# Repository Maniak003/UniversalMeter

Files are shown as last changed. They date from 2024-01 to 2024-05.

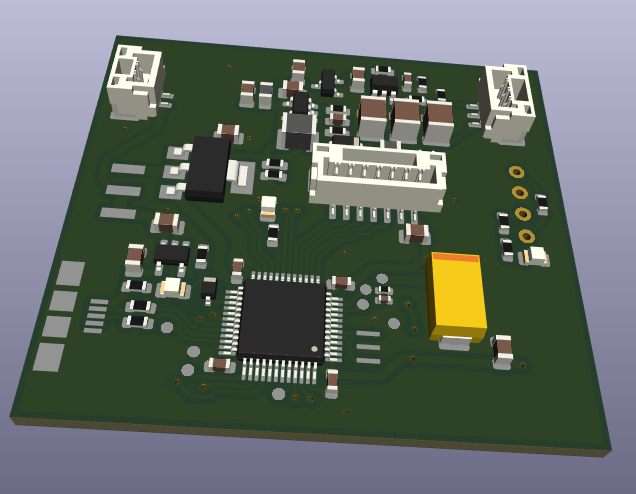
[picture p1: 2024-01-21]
Documents/bot_board.png

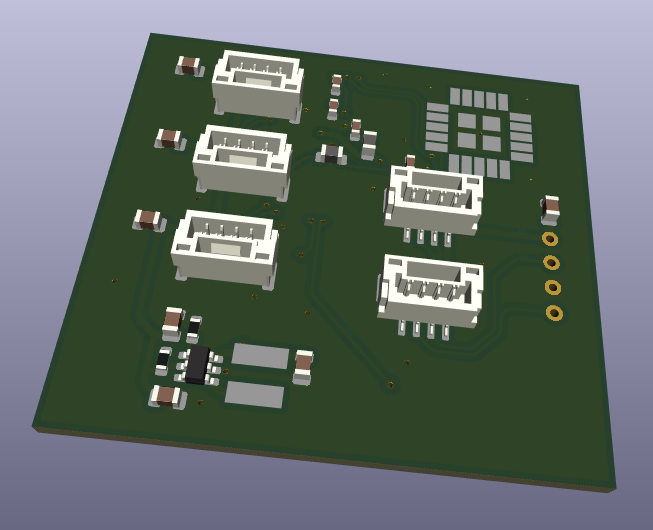
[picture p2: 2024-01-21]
Documents/top_board.png

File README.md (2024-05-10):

<!DOCTYPE html>
<html lang="en" data-color-mode="auto" data-light-theme="light" data-dark-theme="dark">
  <head>
    <meta charset="utf-8">
  </head>
    <body class="logged-in env-production page-responsive page-blob" style="word-wrap: break-word;">
      <p> Many sensors in one device.</p>
      <a href="https://github.com/Maniak003/UniversalMeter/wiki/Description" rel="nofollow">
        BluZ
      </a>
    </body>
</html>

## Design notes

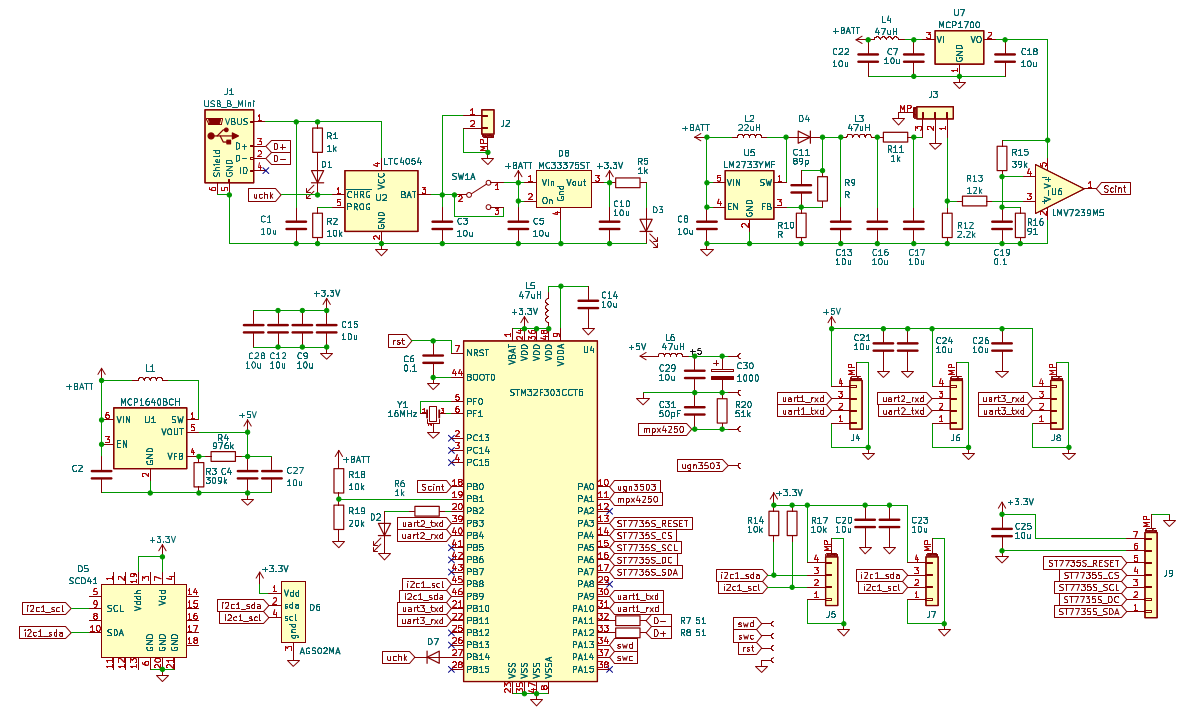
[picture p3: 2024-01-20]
kicad/AirAnalizer/AirAnalizer.png

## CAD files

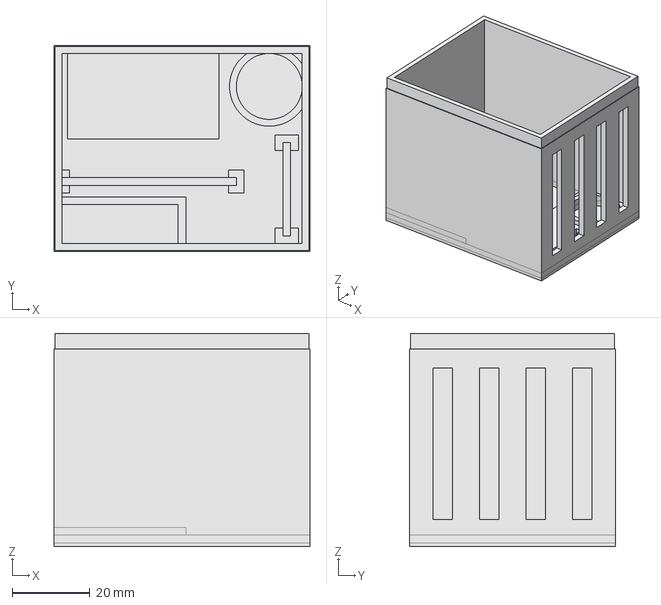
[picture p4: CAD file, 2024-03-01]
FreeCAD/base.FCStd
66.0 x 53.0 x 55.0 mm

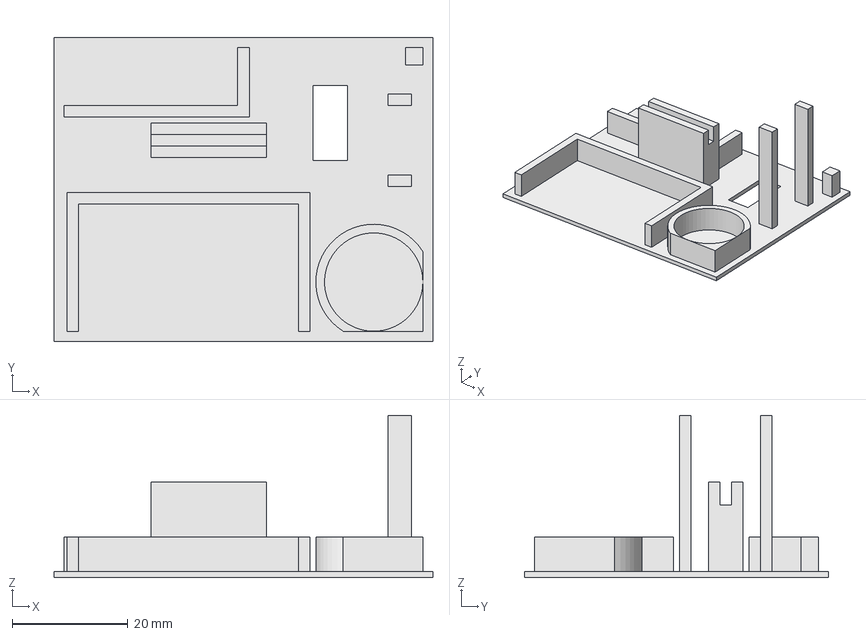
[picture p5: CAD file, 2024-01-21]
FreeCAD/base_top.FCStd
65.5 x 52.5 x 28.0 mm

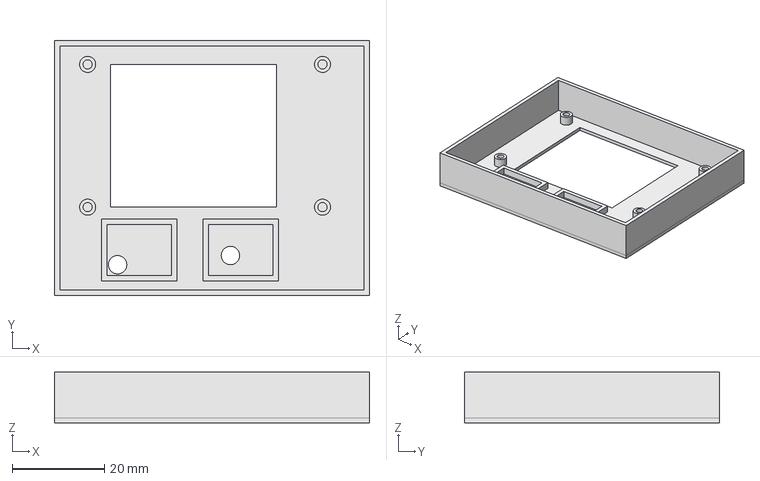
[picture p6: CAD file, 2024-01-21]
FreeCAD/cover.FCStd
68.4 x 55.4 x 11.0 mm

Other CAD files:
FreeCAD/base2.stl
FreeCAD/base.stl
FreeCAD/cover.stl

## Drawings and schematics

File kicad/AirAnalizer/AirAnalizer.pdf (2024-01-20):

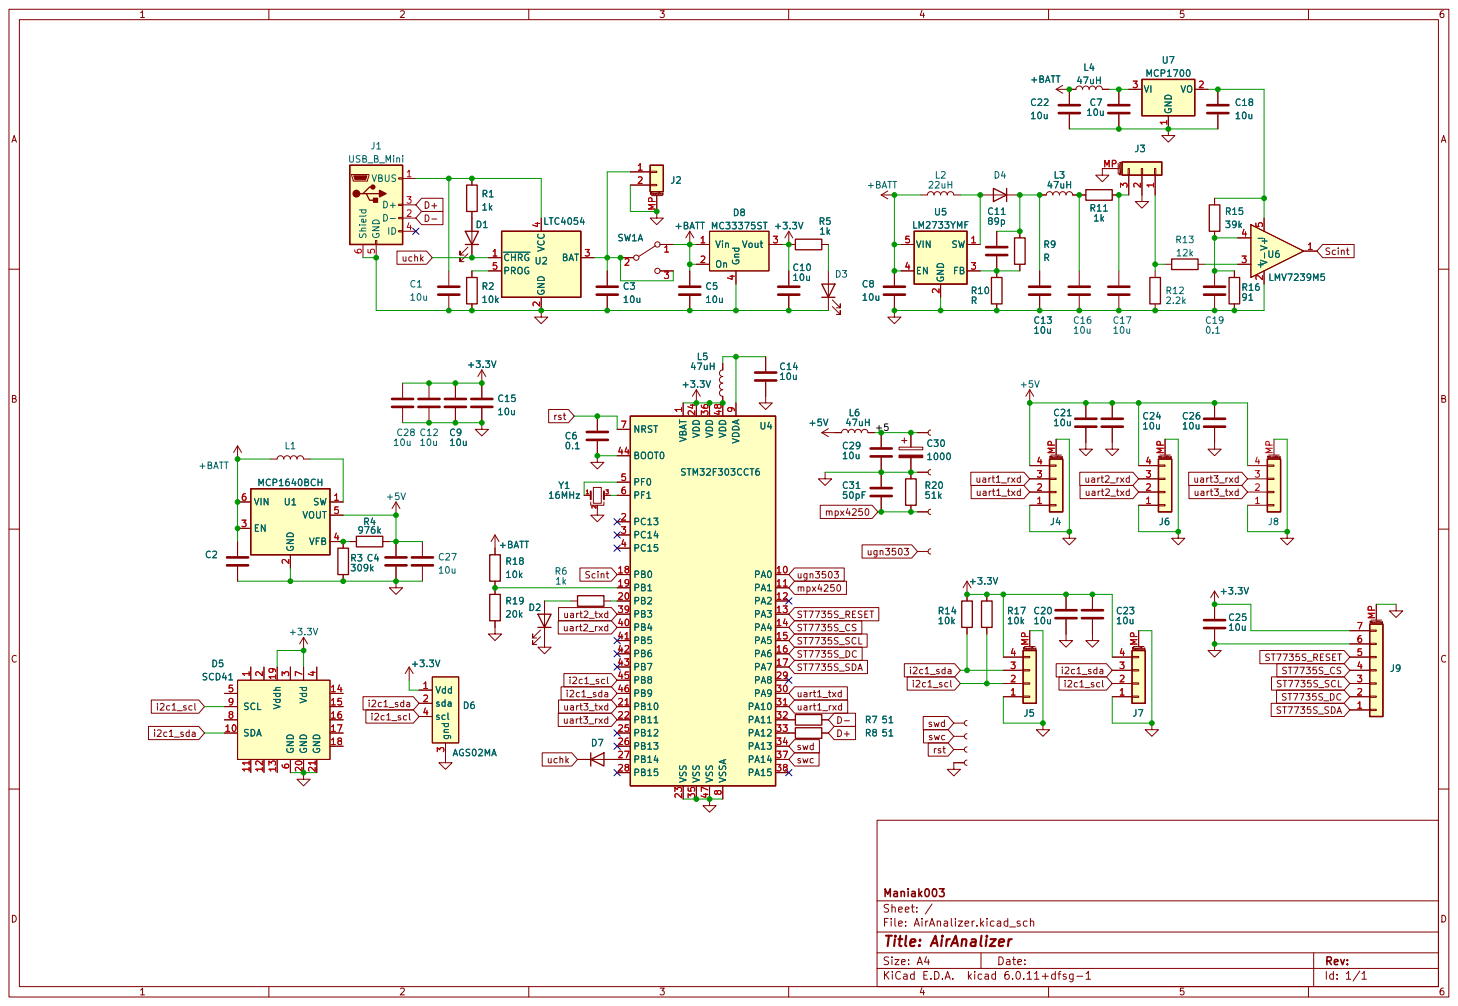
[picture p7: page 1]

1 VO 2 VI 3 U7 MCP1700 SW 1 GND

Id: 1/1 Title: AirAnalizer File: AirAnalizer.kicad_sch Sheet: / Maniak003

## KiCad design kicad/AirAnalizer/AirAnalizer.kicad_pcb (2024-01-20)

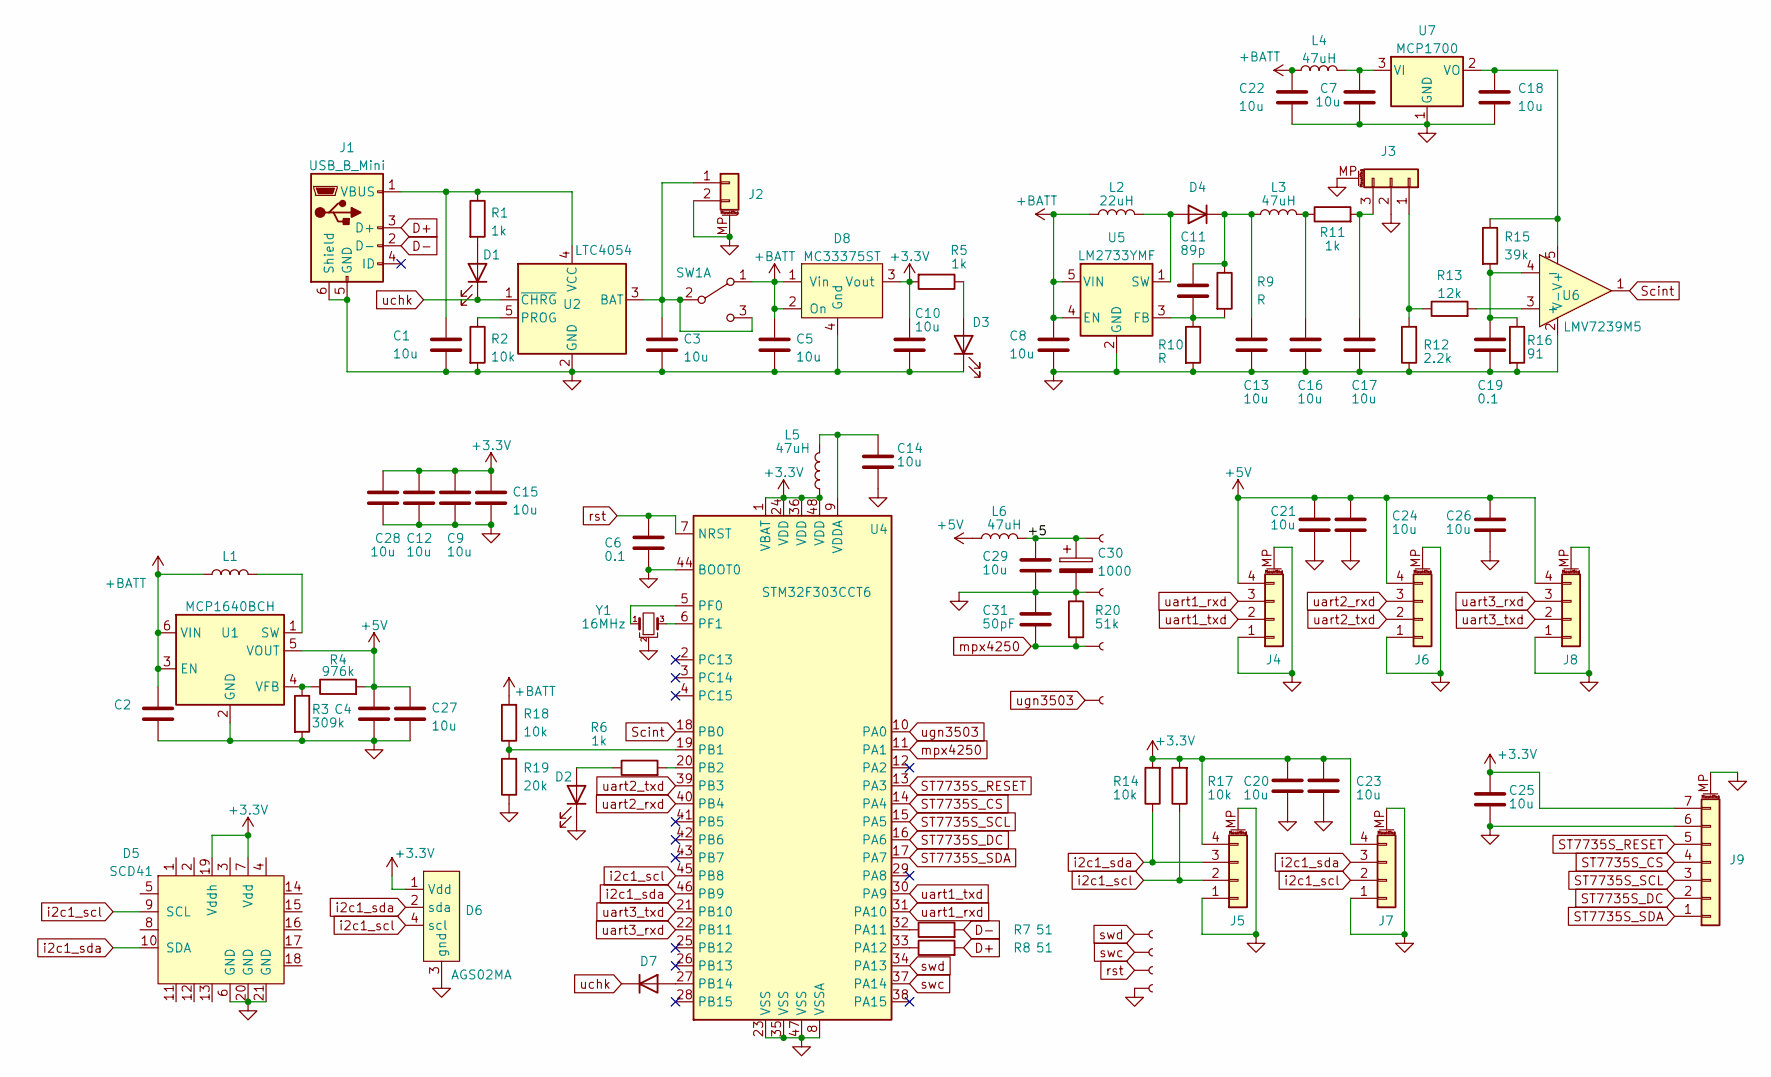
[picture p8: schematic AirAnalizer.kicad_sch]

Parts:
C1, C3, C5, C7, C8, C12, C15, C18, C21, C22, C23, C24, C26, C27: 10u; C_0805_2012Metric
C2, C4: C; C_0805_2012Metric
C6, C19: 0.1; C_0603_1608Metric
C9, C10, C14, C20, C25, C28, C29: 10u; C_0603_1608Metric
C11: 89p; C_0603_1608Metric
C13, C16, C17: 10u; C_1210_3225Metric
C30: 1000; CP_EIA-7343-30_AVX-N
C31: 50pF; C_0402_1005Metric
D1, D2, D3: LED; LED_0805_2012Metric
D4: D; D_SOD-123
D5: SCD41
D6: AGS02MA
D7: D; D_SOD-323
D8: MC33375ST; SOT-223
J1: USB_B_Mini; USB_Micro-B_Amphenol_10104110_Horizontal
J2: Conn_01x02_MountingPin; JST_GH_BM02B-GHS-TBT_1x02-1MP_P1.25mm_Vertical
J3: Conn_01x03_MountingPin; JST_GH_BM03B-GHS-TBT_1x03-1MP_P1.25mm_Vertical
J4, J5, J6, J7, J8: Conn_01x04_MountingPin; JST_GH_BM04B-GHS-TBT_1x04-1MP_P1.25mm_Vertical
J9: Conn_01x07_MountingPin; JST_GH_BM07B-GHS-TBT_1x07-1MP_P1.25mm_Vertical
J10, J11, J12, J13, J14, J15, J16: Conn; conn_mini
J17: Conn; mini_conn
L1: 4.7uH; L_Ferrocore_DLG-0403
L2: 22uH; L_1210_3225Metric
L3, L4, L5, L6: 47uH; L_0805_2012Metric
R1, R5, R6, R11: 1k; R_0603_1608Metric
R2, R14, R17, R18: 10k; R_0603_1608Metric
R3: 309k; R_0603_1608Metric
R4: 976k; R_0603_1608Metric
R7, R8: 51; R_0603_1608Metric
R9, R10: R; R_0603_1608Metric
R12: 2.2k; R_0603_1608Metric
R13: 12k; R_0603_1608Metric
R15: 39k; R_0603_1608Metric
R16: 91; R_0603_1608Metric
R19: 20k; R_0603_1608Metric
R20: 51k; R_0402_1005Metric
SW1: SW_DPDT_x2; MySwithc
U1: MCP1640BCH; SOT-23-6
U2: LTC4054; TSOT-23-5
U4: STM32F303CCT6; LQFP-48_7x7mm_P0.5mm
U5: LM2733YMF; SOT-23-5
U6: LMV7239M5; SOT-23-5
U7: MCP1700; SOT-23
Y1: 16MHz; Resonator_SMD_Murata_CSTxExxV-3Pin_3.0x1.1mm

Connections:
+3.3V: C9.1, C10.1, C12.1, C15.1, C20.1, C23.1, C25.1, C28.1, D5.7 (Vdd), D5.19 (Vddh), D6.1 (Vdd), D8.3 (Vout), J5.4, J7.4, J9.7, L5.1, R5.2, R14.2, R17.2, U4.1 (VBAT), U4.24 (VDD), U4.36 (VDD), U4.48 (VDD)
+5V: C4.1, C21.1, C24.1, C26.1, C27.1, J4.4, J6.4, J8.4, L6.1, R4.2, U1.5 (VOUT)
+BATT: C2.1, C5.1, C8.1, C22.1, D8.1 (Vin), D8.2 (On), L1.1, L2.1, L4.1, R18.2, SW1.1 (A), U1.3 (EN), U1.6 (VIN), U5.4 (EN), U5.5 (VIN)
/+5: C29.1, C30.1, J16.1, L6.2
D+: J1.3 (D+), R8.2
D-: J1.2 (D-), R7.2
GND: C1.2, C2.2, C3.2, C4.2, C5.2, C6.2, C7.2, C8.2, C9.2, C10.2, C12.2, C13.2, C14.2, C15.2, C16.2, C17.2, C18.2, C19.2, C20.2, C21.2, C22.2, C23.2, C24.2, C25.2, C26.2, C27.2, C28.2, C29.2, C30.2, C31.1, D2.1 (K), D3.1 (K), D5.6 (GND), D5.20 (GND), D5.21 (GND), D6.3 (gnd), D8.4 (Gnd), J1.5 (GND), J1.6 (Shield), J2.2, J2.MP (MountPin), J3.2, J3.MP (MountPin), J4.1, J4.MP (MountPin), J5.1, J5.MP (MountPin), J6.1, J6.MP (MountPin), J7.1, J7.MP (MountPin), J8.1, J8.MP (MountPin), J9.6, J9.MP (MountPin), J13.1, J15.1, R2.2, R3.2, R10.2, R12.1, R16.2, R19.1, R20.1, U1.2 (GND), U2.2 (GND), U4.8 (VSSA), U4.23 (VSS), U4.35 (VSS), U4.44 (BOOT0), U4.47 (VSS), U5.2 (GND), U6.2 (V-), U7.1 (GND), Y1.2
unnamed: C1.1, J1.1 (VBUS), R1.1, U2.4 (VCC)
unnamed: C3.1, J2.1, SW1.2 (B), SW1.3 (C), U2.3 (BAT)
unnamed: C7.1, L4.2, U7.3 (VI)
unnamed: C11.1, C13.1, D4.1 (K), L3.1, R9.1
unnamed: C11.2, R9.2, R10.1, U5.3 (FB)
unnamed: C14.1, L5.2, U4.9 (VDDA)
unnamed: C16.1, L3.2, R11.1
unnamed: C17.1, J3.3, R11.2
unnamed: C18.1, R15.1, U6.5 (V+), U7.2 (VO)
unnamed: C19.1, R15.2, R16.1, U6.4 (-)
unnamed: D1.2 (A), R1.2
unnamed: D2.2 (A), R6.1
unnamed: D3.2 (A), R5.1
unnamed: D4.2 (A), L2.2, U5.1 (SW)
unnamed: D7.2 (A), U4.27 (PB14)
unnamed: J3.1, R12.2, R13.1
unnamed: L1.2, U1.1 (SW)
unnamed: R2.1, U2.5 (PROG)
unnamed: R3.1, R4.1, U1.4 (VFB)
unnamed: R6.2, U4.20 (PB2)
unnamed: R7.1, U4.32 (PA11)
unnamed: R8.1, U4.33 (PA12)
unnamed: R13.2, U6.3 (+)
unnamed: R18.1, R19.2, U4.19 (PB1)
unnamed: U4.5 (PF0), Y1.1
unnamed: U4.6 (PF1), Y1.3
ST7735S_CS: J9.4, U4.14 (PA4)
ST7735S_DC: J9.2, U4.16 (PA6)
ST7735S_RESET: J9.5, U4.13 (PA3)
ST7735S_SCL: J9.3, U4.15 (PA5)
ST7735S_SDA: J9.1, U4.17 (PA7)
Scint: U4.18 (PB0), U6.1
i2c1_scl: D5.9 (SCL), D6.4 (scl), J5.2, J7.2, R17.1, U4.45 (PB8)
i2c1_sda: D5.10 (SDA), D6.2 (sda), J5.3, J7.3, R14.1, U4.46 (PB9)
mpx4250: C31.2, J14.1, R20.2, U4.11 (PA1)
rst: C6.1, J12.1, U4.7 (NRST)
swc: J11.1, U4.37 (PA14)
swd: J10.1, U4.34 (PA13)
uart1_rxd: J4.3, U4.31 (PA10)
uart1_txd: J4.2, U4.30 (PA9)
uart2_rxd: J6.3, U4.40 (PB4)
uart2_txd: J6.2, U4.39 (PB3)
uart3_rxd: J8.3, U4.22 (PB11)
uart3_txd: J8.2, U4.21 (PB10)
uchk: D1.1 (K), D7.1 (K), U2.1 (~CHRG)
ugn3503: J17.1, U4.10 (PA0)

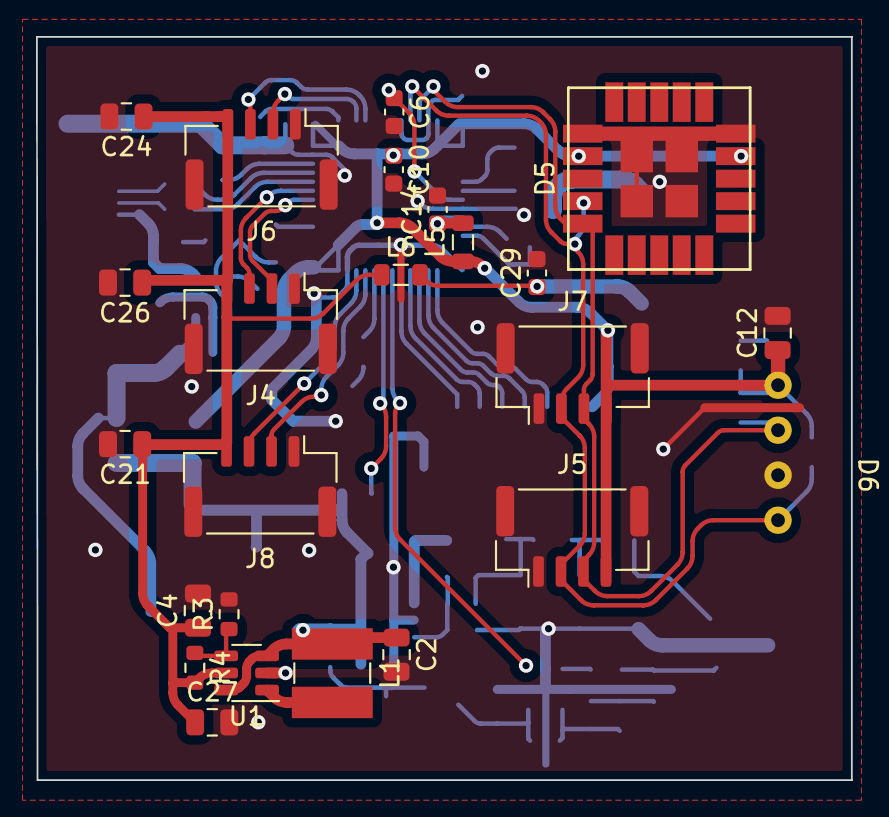
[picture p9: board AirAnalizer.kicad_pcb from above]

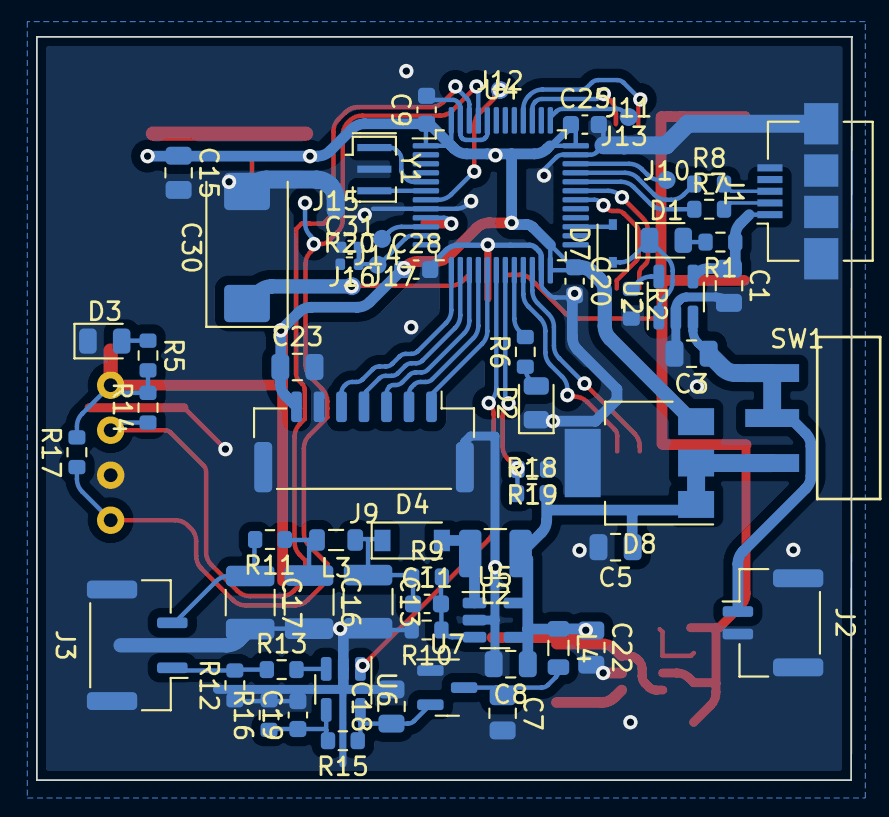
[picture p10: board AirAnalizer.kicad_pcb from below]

Board: 2 copper layers, 45.3 x 41.3 mm, 90 parts (66 on the bottom side), 53 nets.

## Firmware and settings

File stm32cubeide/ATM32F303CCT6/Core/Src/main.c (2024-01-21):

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
/* Includes ------------------------------------------------------------------*/
#include "main.h"

/* USER CODE BEGIN PD */
uint32_t CO2Counter, CO2Interval, scint_counter = 0, scint_timer, battaryLevel = 0 ;
uint16_t CO2;
sSensorMeasurement_t messuremetData;
char text1306[18];
uint16_t ze08_value;
//uint8_t Data_Buffer[9];
uint8_t PM25_buffer[32];
float temperature, pressure, humidity, bataryValue = 0, soundPress = 48.2f, MAX44009_lux = 1150;
/* USER CODE END PD */

ADC_HandleTypeDef hadc3;
DMA_HandleTypeDef hdma_adc3;

I2C_HandleTypeDef hi2c1;

SPI_HandleTypeDef hspi1;

TIM_HandleTypeDef htim4;

UART_HandleTypeDef huart1;
UART_HandleTypeDef huart2;

void SystemClock_Config(void);
static void MX_GPIO_Init(void);
static void MX_DMA_Init(void);
static void MX_SPI1_Init(void);
static void MX_I2C1_Init(void);
static void MX_TIM4_Init(void);
static void MX_USART2_UART_Init(void);
static void MX_USART1_UART_Init(void);
static void MX_ADC3_Init(void);
/**
  * @brief  The application entry point.
  * @retval int
  */
int main(void)
{
  /* MCU Configuration--------------------------------------------------------*/

  /* Reset of all peripherals, Initializes the Flash interface and the Systick. */
  HAL_Init();

  /* Configure the system clock */
  SystemClock_Config();

  /* Initialize all configured peripherals */
  MX_GPIO_Init();
  MX_DMA_Init();
  MX_SPI1_Init();
  MX_I2C1_Init();
  MX_TIM4_Init();
  MX_USART2_UART_Init();
  MX_USART1_UART_Init();
  MX_ADC3_Init();
  /* USER CODE BEGIN 2 */

  HAL_TIM_Base_Start_IT(&htim4);
  HAL_GPIO_WritePin(LED_GPIO_Port, LED_Pin, GPIO_PIN_SET);
	//HAL_Delay(10);
	//HAL_GPIO_WritePin(LED_GPIO_Port, LED_Pin, GPIO_PIN_RESET);

  uint16_t serialBufer[3];
  serialBufer[0] = 0;
  serialBufer[1] = 0;
  serialBufer[2] = 0;

  ST7735_Init();
  ST7735_FillScreen(ST7735_BLACK);

  ST7735_WriteString(0, 0, "SCD41 init  ", Font_7x10, ST7735_WHITE, ST7735_BLACK);
  moduleReinit();
  enablePeriodMeasure(SCD4X_STOP_PERIODIC_MEASURE);  // Write: C4 0 D:3F 0 D:86 0
  HAL_Delay(500);
  if (getSerialNumber(serialBufer)) { // Write: C4 0 D:36 0 D:82 0 Read: C5 0 D:EA 0 D:AE 0 D:FA 0 D:B7 0 D:07 0 D:29 0 D:3B 0 D:BF Write: C4 0 D:21 0 D:B1 0
	ST7735_WriteString(96, 0, "Ok", Font_7x10, ST7735_GREEN, ST7735_BLACK);
  } else {
	ST7735_WriteString(96, 0, "Fail", Font_7x10, ST7735_RED, ST7735_BLACK);
  }
  enablePeriodMeasure(SCD4X_START_PERIODIC_MEASURE);

  ST7735_WriteString(0, 11, "BME280 init ", Font_7x10, ST7735_WHITE, ST7735_BLACK);
  BME280_Init();
  ST7735_WriteString(96, 11, "Ok", Font_7x10, ST7735_GREEN, ST7735_BLACK);

  uint32_t vvv = AGS02MA_getFirmwareVersion();
  sprintf(text1306, "VER:%lu  ", vvv);
  ST7735_WriteString(0, 44, text1306, Font_7x10, ST7735_WHITE, ST7735_BLACK);

  HAL_Delay(500);
  ST7735_FillScreen(ST7735_BLACK);
  CO2Interval = MEAS_CO2_INTERVAL2;
  CO2Counter = HAL_GetTick();
  scint_counter = 0;
  scint_timer = CO2Counter;

  MAX44009_Init(&MAX44009_PORT);
  MAX44009_ContinuousMode(1);

  /* USER CODE END 2 */

  /* Infinite loop */
  /* USER CODE BEGIN WHILE */
  while (1)
  {
	  	if (HAL_GetTick() - CO2Counter > CO2Interval) {
	  		CO2Counter = HAL_GetTick();
	  		readMeasurement(&messuremetData);
			if (messuremetData.CO2ppm > 0) {
				CO2 = messuremetData.CO2ppm;
				CO2Interval = MEAS_CO2_INTERVAL2;
			} else {
				CO2Interval = MEAS_CO2_INTERVAL1;
			}
			sprintf(text1306, "CO2:%dppm  ", CO2);
			if (CO2 < CO2_NOMINAL) {
				ST7735_WriteString(0, 0, text1306, Font_7x10, ST7735_GREEN, ST7735_BLACK);
			} else if (CO2 < CO2_MAXIMUM) {
				ST7735_WriteString(0, 0, text1306, Font_7x10, ST7735_YELLOW, ST7735_BLACK);
			} else {
				ST7735_WriteString(0, 0, text1306, Font_7x10, ST7735_RED, ST7735_BLACK);
			}
	  	}

	  	//memset(text1306, 0, sizeof(text1306));
	  	if (HAL_GetTick() - scint_timer > 0 ) {
			float mmm = (float) scint_counter / (float) (HAL_GetTick() - scint_timer) * 1000.0f;
			sprintf(text1306, "cps:%.2f %.1f%% ", mmm , 300.f / sqrt((float) scint_counter));
			if (mmm < NORMAL_LEVEL) {
				ST7735_WriteString(0, 11, text1306, Font_7x10, ST7735_GREEN, ST7735_BLACK);
			} else if (mmm < WARN_LEVEL) {
				ST7735_WriteString(0, 11, text1306, Font_7x10, ST7735_YELLOW, ST7735_BLACK);
			} else if (mmm < CRIT_LEVEL) {
				ST7735_WriteString(0, 11, text1306, Font_7x10, ST7735_RED, ST7735_BLACK);
			} else {
				ST7735_WriteString(0, 11, text1306, Font_7x10, ST7735_MAGENTA, ST7735_BLACK);
			}
		}

		temperature = BME280_ReadTemperature();
		pressure = BME280_ReadPressure() * 0.00750063755419211f; //0.00750063755419211
		humidity = BME280_ReadHumidity();
		sprintf(text1306, "T:%.0fC P:%.0f H:%.0f%% ", temperature, pressure, humidity);
		ST7735_WriteString(0, 22, text1306, Font_7x10, ST7735_WHITE, ST7735_BLACK);

		/* TVOC
		 *  Норма содержания летучих веществ в воздухе - до 0.5 mg/m3
		 *  0.8 mg/m3 -- предельное значение.
		 */
		if (HAL_GetTick() > TVOC_TIMEOUT) {
			uint32_t tvoc = AGS02MA_getTVOC();
			sprintf(text1306, "TVOC:%luppb   ", tvoc);
			if (tvoc < NORMAL_TVOC_LEVEL) {
				ST7735_WriteString(0, 33, text1306, Font_7x10, ST7735_GREEN, ST7735_BLACK);
			} else if (tvoc < WARN_TVOC_LEVEL) {
				ST7735_WriteString(0, 33, text1306, Font_7x10, ST7735_YELLOW, ST7735_BLACK);
			} else {
				ST7735_WriteString(0, 33, text1306, Font_7x10, ST7735_RED, ST7735_BLACK);
			}
		} else {
			uint16_t tmout = (TVOC_TIMEOUT - HAL_GetTick()) / 1000;
			sprintf(text1306, "TVOC:WrmUP(%u)  ", tmout);
			ST7735_WriteString(0, 33, text1306, Font_7x10, ST7735_WHITE, ST7735_BLACK);
		}

		/* ZE08
		 * https://gazoanalizators.ru/converter/
		 * 1 ppm формальдегида CH2O равен 1.24577 мг/м3
		 * Средне-суточная ПДК концентрация -- 0.003 мг/м3 0.0024ppm
		 * Разовая ПДК 0,035 мг/м3 -- 0.02803ppm
		 * */

		if((ze08_value = ZE08_readData()) != 0xFFFF) {
			/*
			//ze08_value = ZE08_readData(Data_Buffer, sizeof(Data_Buffer));

			for (int iii = 0; iii < sizeof(Data_Buffer) - 3; iii++) {
				sprintf(text1306, "%2x", Data_Buffer[iii]);
				ST7735_WriteString(iii * 16, 44, text1306, Font_7x10, ST7735_WHITE, ST7735_BLACK);
			}*/
			sprintf(text1306, "CH2O:%uppb     ", ze08_value);
			if (ze08_value < NORMAL_CH2O) {
				ST7735_WriteString(0, 44, text1306, Font_7x10, ST7735_GREEN, ST7735_BLACK);
			} else if (ze08_value < WARN_CH2O) {
				ST7735_WriteString(0, 44, text1306, Font_7x10, ST7735_YELLOW, ST7735_BLACK);
			} else {
				ST7735_WriteString(0, 44, text1306, Font_7x10, ST7735_RED, ST7735_BLACK);
			}
			//	ST7735_WriteString(0, 44, "CH2O: N/A     ", Font_7x10, ST7735_WHITE, ST7735_BLACK);
			//}
		}

		/* PM25*/

		if (PM25_GetData(PM25_buffer, sizeof(PM25_buffer))) {
/*
		for (int iii = 0; iii < sizeof(PM25_buffer); iii++) {
			sprintf(text1306, "%2x", PM25_buffer[iii]);
			ST7735_WriteString(iii * 16, 55, text1306, Font_7x10, ST7735_WHITE, ST7735_BLACK);
		}
*/
			uint16_t part03  = PM25_buffer[16] << 8 | PM25_buffer[17];
			uint16_t part05  = PM25_buffer[18] << 8 | PM25_buffer[19];
			uint16_t part10  = PM25_buffer[20] << 8 | PM25_buffer[21];
			uint16_t part25  = PM25_buffer[22] << 8 | PM25_buffer[23];
			uint16_t part50  = PM25_buffer[24] << 8 | PM25_buffer[25];
			uint16_t part100 = PM25_buffer[26] << 8 | PM25_buffer[27];

			sprintf(text1306, "PM0.3 :%u  ", part03);
			ST7735_WriteString(0, 55, text1306, Font_7x10, ST7735_WHITE, ST7735_BLACK);
			sprintf(text1306, "PM0.5 :%u  ", part05);
			ST7735_WriteString(0, 66, text1306, Font_7x10, ST7735_WHITE, ST7735_BLACK);
			sprintf(text1306, "PM1.0 :%u  ", part10);
			ST7735_WriteString(0, 77, text1306, Font_7x10, ST7735_WHITE, ST7735_BLACK);
			sprintf(text1306, "PM2.5 :%u  ", part25);
			ST7735_WriteString(0, 88, text1306, Font_7x10, ST7735_WHITE, ST7735_BLACK);
			sprintf(text1306, "PM5.0 :%u  ", part50);
			ST7735_WriteString(0, 99, text1306, Font_7x10, ST7735_WHITE, ST7735_BLACK);
			sprintf(text1306, "PM10  :%u  ", part100);
			ST7735_WriteString(0, 110, text1306, Font_7x10, ST7735_WHITE, ST7735_BLACK);
		}

		/* Напряжение источника питания */
		bataryValue = (float) battaryLevel / 4096 * ADC_L_TUNE;
		if (bataryValue > 3) {
			sprintf(text1306, "%.2f", bataryValue);
		} else {
			sprintf(text1306, "BatL");
		}
		ST7735_WriteString(98, 0, text1306, Font_7x10, ST7735_WHITE, ST7735_BLACK);
		HAL_ADC_Start_DMA(&hadc3, &battaryLevel, 1);


		/* Звуковое давление */
		sprintf(text1306, "Sound :%0.1f db", soundPress);
		ST7735_WriteString(0, 121, text1306, Font_7x10, ST7735_WHITE, ST7735_BLACK);

		/* Освещенность */
		if(MAX44009_OK == MAX44009_ReadLightHighResolution(&MAX44009_lux)) {
			sprintf(text1306, "Illum :%0.1f lux   ", MAX44009_lux);
		} else {
			sprintf(text1306, "Illum :%0.0f lux   ", 0.0f);
		}
		ST7735_WriteString(0, 132, text1306, Font_7x10, ST7735_WHITE, ST7735_BLACK);

		HAL_Delay(1000);
    /* USER CODE END WHILE */

    /* USER CODE BEGIN 3 */
  }
  /* USER CODE END 3 */
}

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


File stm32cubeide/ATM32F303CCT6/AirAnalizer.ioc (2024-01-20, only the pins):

Mcu.UserName=STM32F303CCTx
PA10.Signal=USART1_RX
PA3.GPIO_Label=ST7735S_RESET
PA3.Signal=GPIO_Output
PA4.GPIO_Label=ST7735S_CS
PA4.Signal=GPIO_Output
PA5.Signal=SPI1_SCK
PA6.GPIO_Label=ST7735S_DC
PA6.Signal=GPIO_Output
PA7.Signal=SPI1_MOSI
PA9.Signal=USART1_TX
PB0.Signal=GPXTI0
PB1.GPIO_Label=BAT
PB1.Signal=ADC3_IN1
PB2.GPIO_Label=LED
PB2.Signal=GPIO_Output
PB3.Signal=USART2_TX
PB4.Signal=USART2_RX
PB8.Signal=I2C1_SCL
PB9.Signal=I2C1_SDA
PF0-OSC_IN.Signal=RCC_OSC_IN
PF1-OSC_OUT.Signal=RCC_OSC_OUT

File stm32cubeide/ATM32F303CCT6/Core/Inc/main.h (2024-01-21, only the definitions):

#define ST7735S_RESET_Pin GPIO_PIN_3
#define ST7735S_RESET_GPIO_Port GPIOA
#define ST7735S_CS_Pin GPIO_PIN_4
#define ST7735S_CS_GPIO_Port GPIOA
#define ST7735S_DC_Pin GPIO_PIN_6
#define ST7735S_DC_GPIO_Port GPIOA
#define BAT_Pin GPIO_PIN_1
#define BAT_GPIO_Port GPIOB
#define LED_Pin GPIO_PIN_2
#define LED_GPIO_Port GPIOB
#define MEAS_CO2_INTERVAL1 1000
#define MEAS_CO2_INTERVAL2 5000
#define CO2_NOMINAL 800.0f
#define CO2_MAXIMUM 1000.0f
#define NORMAL_LEVEL 30.0f
#define WARN_LEVEL 50.0f
#define CRIT_LEVEL 100.0f
#define DIV_PULSE_LED 10
#define ADC_L_TUNE 5.70f
#define NORMAL_TVOC_LEVEL 100
#define WARN_TVOC_LEVEL 1000
#define TVOC_TIMEOUT 120000
#define NORMAL_CH2O 3 //2.4f
#define WARN_CH2O 28 //28.03f

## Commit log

2024-01-20 новый файл: Documents/MPX4250.PDF новый файл: Documents/PMS5003-Series-Manual.pdf новый файл: Documents/SS49E.pdf новый файл: Documents/UGN3503U.PDF новый файл: "Documents/\320\226\320\265\320\275\32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
    [AirAnalizer.kicad_pcb, AirAnalizer.kicad_sch, base.FCStd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]
2024-01-20 новый файл: kicad/AirAnalizer/AirAnalizer.pdf новый файл: kicad/AirAnalizer/AirAnalizer.png
2024-01-21 изменено: FreeCAD/base.FCStd изменено: FreeCAD/base.FCStd1 удалено: kicad/AirAnalizer/AirAnalizer-backups/AirAnalizer-2023-11-27_121647.zip удалено: kicad/AirAnalizer/AirAnalizer-backups/AirAnalizer-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
    [base.FCStd]
2024-01-21 новый файл: FreeCAD/base_top.FCStd новый файл: FreeCAD/cover.FCStd новый файл: FreeCAD/cover.stl новый файл: stm32cubeide/ATM32F303CCT6/Core/Inc/i2c.h новый файл: stm32cubeide/ATM32F303CCT6/Core/Inc/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
    [base_top.FCStd, cover.FCStd, cover.stl]
2024-01-21 новый файл: Documents/bot_board.png новый файл: Documents/top_board.png изменено: FreeCAD/base.FCStd изменено: FreeCAD/base.FCStd1 изменено: FreeCAD/base.stl новый файл: FreeCAD/base2.stl изменено: F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
    [base.FCStd, base.stl, base2.stl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]
2024-03-01 изменено: FreeCAD/base.FCStd изменено: FreeCAD/base.FCStd1 изменено: FreeCAD/base.stl удалено: kicad/AirAnalizer/AirAnalizer-backups/AirAnalizer-2023-12-22_111938.zip
    [base.FCStd, base.stl]
2024-05-10 новый файл: Documents/UniversalMeter.png изменено: README.md

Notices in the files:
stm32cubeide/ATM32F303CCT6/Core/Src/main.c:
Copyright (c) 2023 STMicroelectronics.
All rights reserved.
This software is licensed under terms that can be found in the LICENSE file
